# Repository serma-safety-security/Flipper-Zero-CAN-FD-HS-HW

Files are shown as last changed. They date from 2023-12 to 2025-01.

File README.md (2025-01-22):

# Flipper Zero CAN HS/FD Adapter

<div align="center">
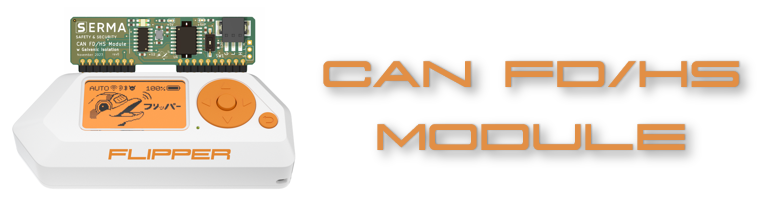
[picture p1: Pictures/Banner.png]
Banner
  
</div>

## Description: 

This project aims to develop a CAN (Controller Area Network) adapter for the Flipper Zero, allowing users to connect devices with a CAN interfaces in particular automotive ECU's.

## Firmware Development:

* The CAN adapter application firmware is developed in C++ using the Flipper Zero's Xtreme-Firmware SDK.
* The application firmware must runs on the Flipper Zero, which communicates with the CAN adapter through its SPI interface.

* Firmware features:
	- [x] CAN HS Communication
	- [ ] CAN FD Communication (partially)
    - [x] Device detection and configuration
	- [x] Error handling and debugging tools

* The CAN adapter is fully compatible with Linux SocketCAN enabling the usage of can-utils tooling for receiving and sending CAN messages. 

[See Software development folder for more information](https://github.com/serma-safety-security/Flipper-Zero-CAN-FD-HS-SW) 

## Hardware Development:

* The CAN adapter board is designed using KiCad 7.x
* The PCB layout includes:
	+ Microchip MCP2518FD CAN transceiver chip
	+ TJ1051i CAN driver with galvanic isolation up to 4kV 
	+ Screwless CAN connector for easy plug-in
	+ TX/RX CAN activity LEDs for easy debugging

[See Hardware development folder for more information](https://github.com/serma-safety-security/Flipper-Zero-CAN-FD-HS-HW/tree/main/Hardware)

## Getting Started:
* Download and install the CAN adapter application
* Launch the application and connect your Flipper Zero into your PC
* Find the appropriate COM port
* Setup the Flipper USB-CAN as a SocketCAN interface :

```sh
sudo modprobe can$ sudo modprobe can-raw$ sudo modprobe slcan
sudo slcan_attach -f -s6 -o “<COM Port> (e.g. :/dev/ttyACM0)”
sudo slcand“<COM Port> (e.g :/dev/ttyACM0)” can0
sudo ifconfig can0 up
```

**Connection:**

<div align="center">
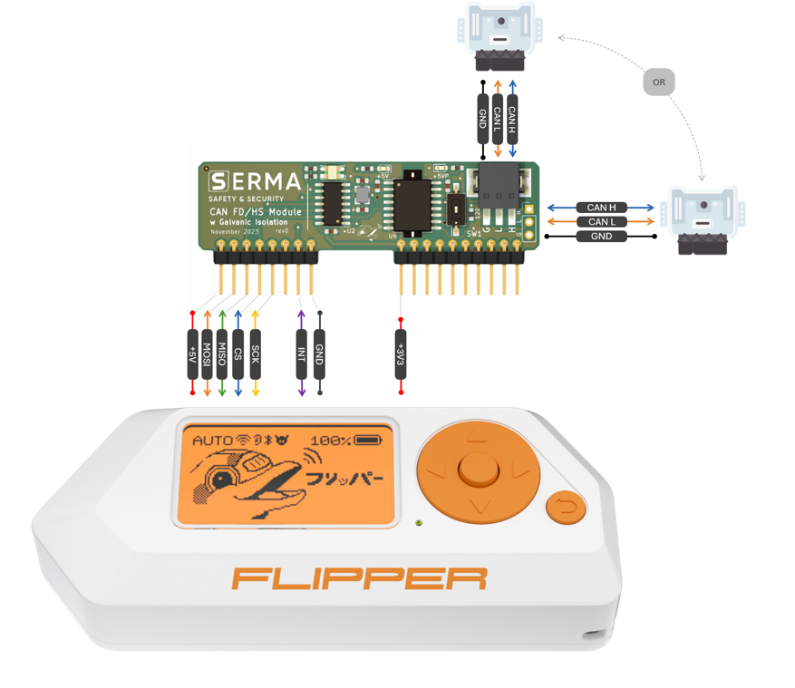
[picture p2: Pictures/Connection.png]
Wiring diagram
  
</div>

## Branches:

* `main`: The main branch, where stable code is kept. This is the default branch that new users will see when they clone the repository.
* `dev`: The development branch, where experimental or feature-in-progress code lives. This allows for concurrent development and testing without affecting the stability of the main branch.

## Contributing:

* Before contributing, please create a new issue to propose your changes.
* Fork this repository to create a copy of the original.
* Create a new branch from `dev` (e.g., `feature/my-new-firmware`) for your feature or fix.
* Make your changes and commit them with descriptive commit messages.
* Push your branch to your forked repository.
* Open a pull request against the original `dev` branch.

## License:

This project is licensed under the MIT See `LICENSE` file for details.

# Acknowledgments:

* Special thanks to Kévin for the SW dev and Morike for the HW dev !

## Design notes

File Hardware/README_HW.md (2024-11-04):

# Flipper Zero CAN FD HS 

<div align="center">
  
</div>

## Table of Contents
1. [Project Overview](#project-overview)
2. [Features](#features)
3. [Hardware Specifications](#hardware-specifications)
4. [Directory Structure](#directory-structure)
5. [Getting Started](#getting-started)
6. [Hardware Design Files](#hardware-design-files)
7. [Bill of Materials (BOM)](#bill-of-materials)
8. [Software & Firmware](#software--firmware)
9. [Testing & Debugging](#testing--debugging)
10. [Contributing](#contributing)
11. [License](#license)
12. [Contact](#contact)

---

## Project Overview

The Flipper Zero CAN FD/HS Module is an open-source hardware project focused on developing a custom electronic board that serves enables Flipper Zero to communicates with devices with a CAN interface. 

This repository contains the hardware design files, including schematics, PCB layout, and other resources necessary for the development and manufacturing of the board.

## Features
  - Supports both CAN 2.0B and CAN FD (up to 8 Mbps)
  - Compact design
  - Low power consumption
  - On-board 5V - 5V DCDC Regulator
  - Galvanic CAN Bus Isolation
  - TX/RX CAN Activity LED
  - Screwless CAN Connector    
 
## Hardware Specifications
- **CAN Controller:** MCP2518FD
- **CAN Transreceiver:** TJA1051i
- **Communication Interfaces:** SPI
- **Power Consumption:** [Idle, Active, etc.]
- **Dimensions:** 68mm x 18mm

## Board Pinout

<div align="center">
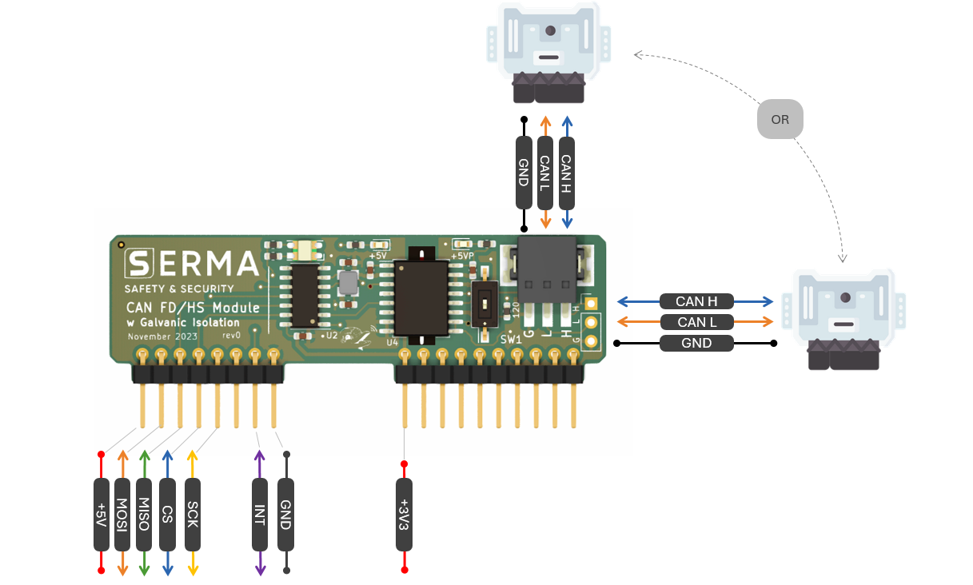
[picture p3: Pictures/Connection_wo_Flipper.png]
Pinout
  
</div>

## Directory Structure
```
├── /docs/                 # Documentation, guides, and tutorials
├── /hardware/             # Schematic, PCB layout files, gerber files
│   ├── /schematics/       # Schematics files (.pdf)
│   ├── /KiCAD Project/    # PCB & Schematic layout files (.brd, .sch)
│   ├── /gerbers/          # Gerber files for manufacturing
├── /bom/                  # Bill of Materials (BOM) files
└── README_HW.md           # Project documentation (this file)
```

## Getting Started
To start working on this project, clone the repository:
```bash
git clone https://github.com/yourusername/electronic-board-project.git
```

### Prerequisites
- **ECAD Tool**: [ See Getting started with Kicad v7 tutorial](https://docs.kicad.org/7.0/en/getting_started_in_kicad/getting_started_in_kicad.html) 

### Installation
1. Open the `Flipper_Zero_CAN_Module.kicad_pro` file using Kicad v7.x
2. Edit the schematic using the Schematic Editor
3. Edit the PCB using the Pcb Editor
3. Export gerber files from the PCB design if you wish to manufacture the board.

## Hardware Design Files
- **Schematic:** [Provide details about the schematic, link to key components, etc.]
- **PCB Layout:**   

<div align="center">
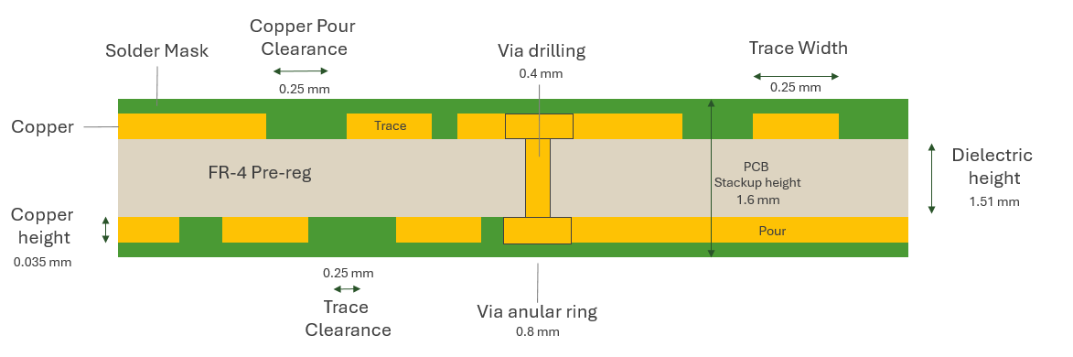
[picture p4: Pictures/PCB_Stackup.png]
PCB stackup
  
</div>

- **Gerber Files:** These files are located in `/hardware/gerbers/` and are used for manufacturing the board.

## Bill of Materials (BOM)

The Bill of Materials (BOM) is located in the `/bom/` folder. This includes a list of all components used in the design along with part numbers, quantities, and suppliers.
- Bills of materials is available for this distributor list : 
  - [x] Mouser
  - [x] LCSC
  - [ ] Radiospare
  
## Software & Firmware
[See Software development folder for more information](https://example.com/redirect) 

## Testing & Debugging
Work in progress..  

## Contributing
Contributions are welcome! Please follow these steps:
1. Fork the repository.
2. Create a new branch: `git checkout -b feature-branch`.
3. Make your changes and commit them.
4. Push to the branch: `git push origin feature-branch`.
5. Submit a pull request.

For large features or changes, consider creating an issue first to discuss the idea.

## License
This project is licensed under the TODO. See the [LICENSE](LICENSE) file for details.

---

Feel free to modify this template based on the specifics of your project!

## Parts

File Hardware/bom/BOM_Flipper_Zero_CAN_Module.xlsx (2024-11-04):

Bill of Materials
Project : | Flipper Zero CAN FD HS |  |  | N° AO : | TBD
Creation Date : | 2024-10-30
Print Date : | 2024-10-30
 |  |  |  |  |  |  | Sourcing 1 |  | Sourcing 2
Item Number | Reference | Description | Value | Quantity | Manufacturer Name | Manufacturer Part Number | Mouser Part Number | Mouser Unit Pricing | LCSC Part Number | LCSC Unit Pricing
1 | C1 | SMD 0603 Unpolarized Capacitor | 100nF | 1 | Murata Electronics | GCM188R71C104JA37D | 81-GCM188R71C104JA7D | 0.214 | C17540711 | 0.1123
 | C2 | SMD 0603 Unpolarized Capacitor | 22pF | 1 | Murata Electronics | GRT0335C1E220GA02D | 81-GRT0335C1E220GA2D | 0.093 | C22197519 | 0.0058
 | C3 | SMD 0603 Unpolarized Capacitor | 22pF | 1 | Murata Electronics | GRT0335C1E220GA02D | 81-GRT0335C1E220GA2D | 0.093 | C22197519 | 0.0058
 | C4 | SMD 0603 Unpolarized Capacitor | 100nF | 1 | Murata Electronics | GCM188R71C104JA37D | 81-GCM188R71C104JA7D | 0.214 | C17540711 | 0.1123
 | C5 | SMD 0603 Unpolarized Capacitor | 100nF | 1 | Murata Electronics | GCM188R71C104JA37D | 81-GCM188R71C104JA7D | 0.214 | C17540711 | 0.1123
 | C6 | SMD 0603 Unpolarized Capacitor | 4.7uF | 1 | Murata Electronics | GRM035R60E475ME01D | 81-GRM035R60E475ME1D | 0.18 | C21794777 | 0.0613
 | D2 | SMD Bicolor LED |  | 1 | Kingbright | KPB-3025ESGC-F01 | 604-KPB-3025ESGC-F01 |  | C5879346 | 0.2588
 | D3 | SMD 0603 Green LED |  | 1 | Vishay Semiconductors | TLMP1100-GS15 | 78-TLMP1100-GS15 | 0.51 | C20430351 | 0.2865
 | D4 | SMD 0603 Green LED |  | 1 | Vishay Semiconductors | TLMP1100-GS15 | 78-TLMP1100-GS15 | 0.51 | C20430351 | 0.2865
 | J1 | SMD 3pins female header | PTSM 0.5/ 3-2.5-H SMD R44 | 1 | Phoenix Contact | 1771033 | 651-1771033 | 0.76 | C3817179 | 0.8832
 | J2 | THT 3 pins 2.54mm male header |  | 1 | Molex | 90120-0123 | 538-90120-0123 | 0.76 | C6356254 | 0.3251
 | L1 | SMD Inductor | 22uH | 1 | TAIYO YUDEN | NRS5020T220MMGJ | 963-NRS5020T220MMGJ | 0.251 | C222921 | 0.146
 | R1 | SMD 0603 Resistor | 280 | 1 | Panasonic | ERJ-UP3F2800V | 667-ERJ-UP3F2800V | 0.223 | C1870036 | 0.0297
 | R2 | SMD 0603 Resistor | 130 | 1 | Panasonic | ERJ-UP3F1300V | 667-ERJ-UP3F1300V | 0.223 | C544047 | 0.0592
 | R3 | SMD 0603 Resistor | 130 | 1 | Panasonic | ERJ-UP3F1300V | 667-ERJ-UP3F1300V | 0.223 | C544047 | 0.0592
 | R4 | SMD 0603 Resistor | 280 | 1 | Panasonic | ERJ-UP3F2800V | 667-ERJ-UP3F2800V | 0.223 | C1870036 | 0.0297
 | R5 | SMD 0603 Resistor | 280 | 1 | Panasonic | ERJ-UP3F2800V | 667-ERJ-UP3F2800V | 0.223 | C1870036 | 0.0297
 | R6 | SMD 0603 Resistor | 120 | 1 | Panasonic | ERJ-P03F1200V | 667-ERJ-P03F1200V | 0.307 | C543223 | 0.0598
 | SW1 | SMD 1-DIP Switch |  | 1 | Omron Electronics | A6S-1104-H | 653-A6S1104H | 2.06 | C19843770 | 0.7302
 | U1 | Flipper Zero |  | 1 |  | FLIPPER_ZERO
 | U2 | SMD CAN FD HS SPI Driver |  | 1 | Microchip | MCP2518FDT-H/SL | 579-MCP2518FDT-H/SL | 1.89 | C626759 | 2.6841
 | U3 | SMD Isolated DC-DC |  | 1 | Murata Power Solutions | NXE1S0505MC | 580-NXE1S0505MC-R13 | 2.86 | C7321470 | 2.6841
 | U4 | SMD Galvanic isolation CAN transreceiver |  | 1 | NXP | TJA1052IT/2Y | 771-TJA1052IT/2Y | 6.36 | C92210
 | Y1 | SMD Oscillator |  | 1 | Abracon | ABM8-40.000MHZ-B2-T | 815-ABM8-40-B2-T | 0.409 |  | 4.2775
Total |  |  |  |  |  |  |  |  |  | 13.2391

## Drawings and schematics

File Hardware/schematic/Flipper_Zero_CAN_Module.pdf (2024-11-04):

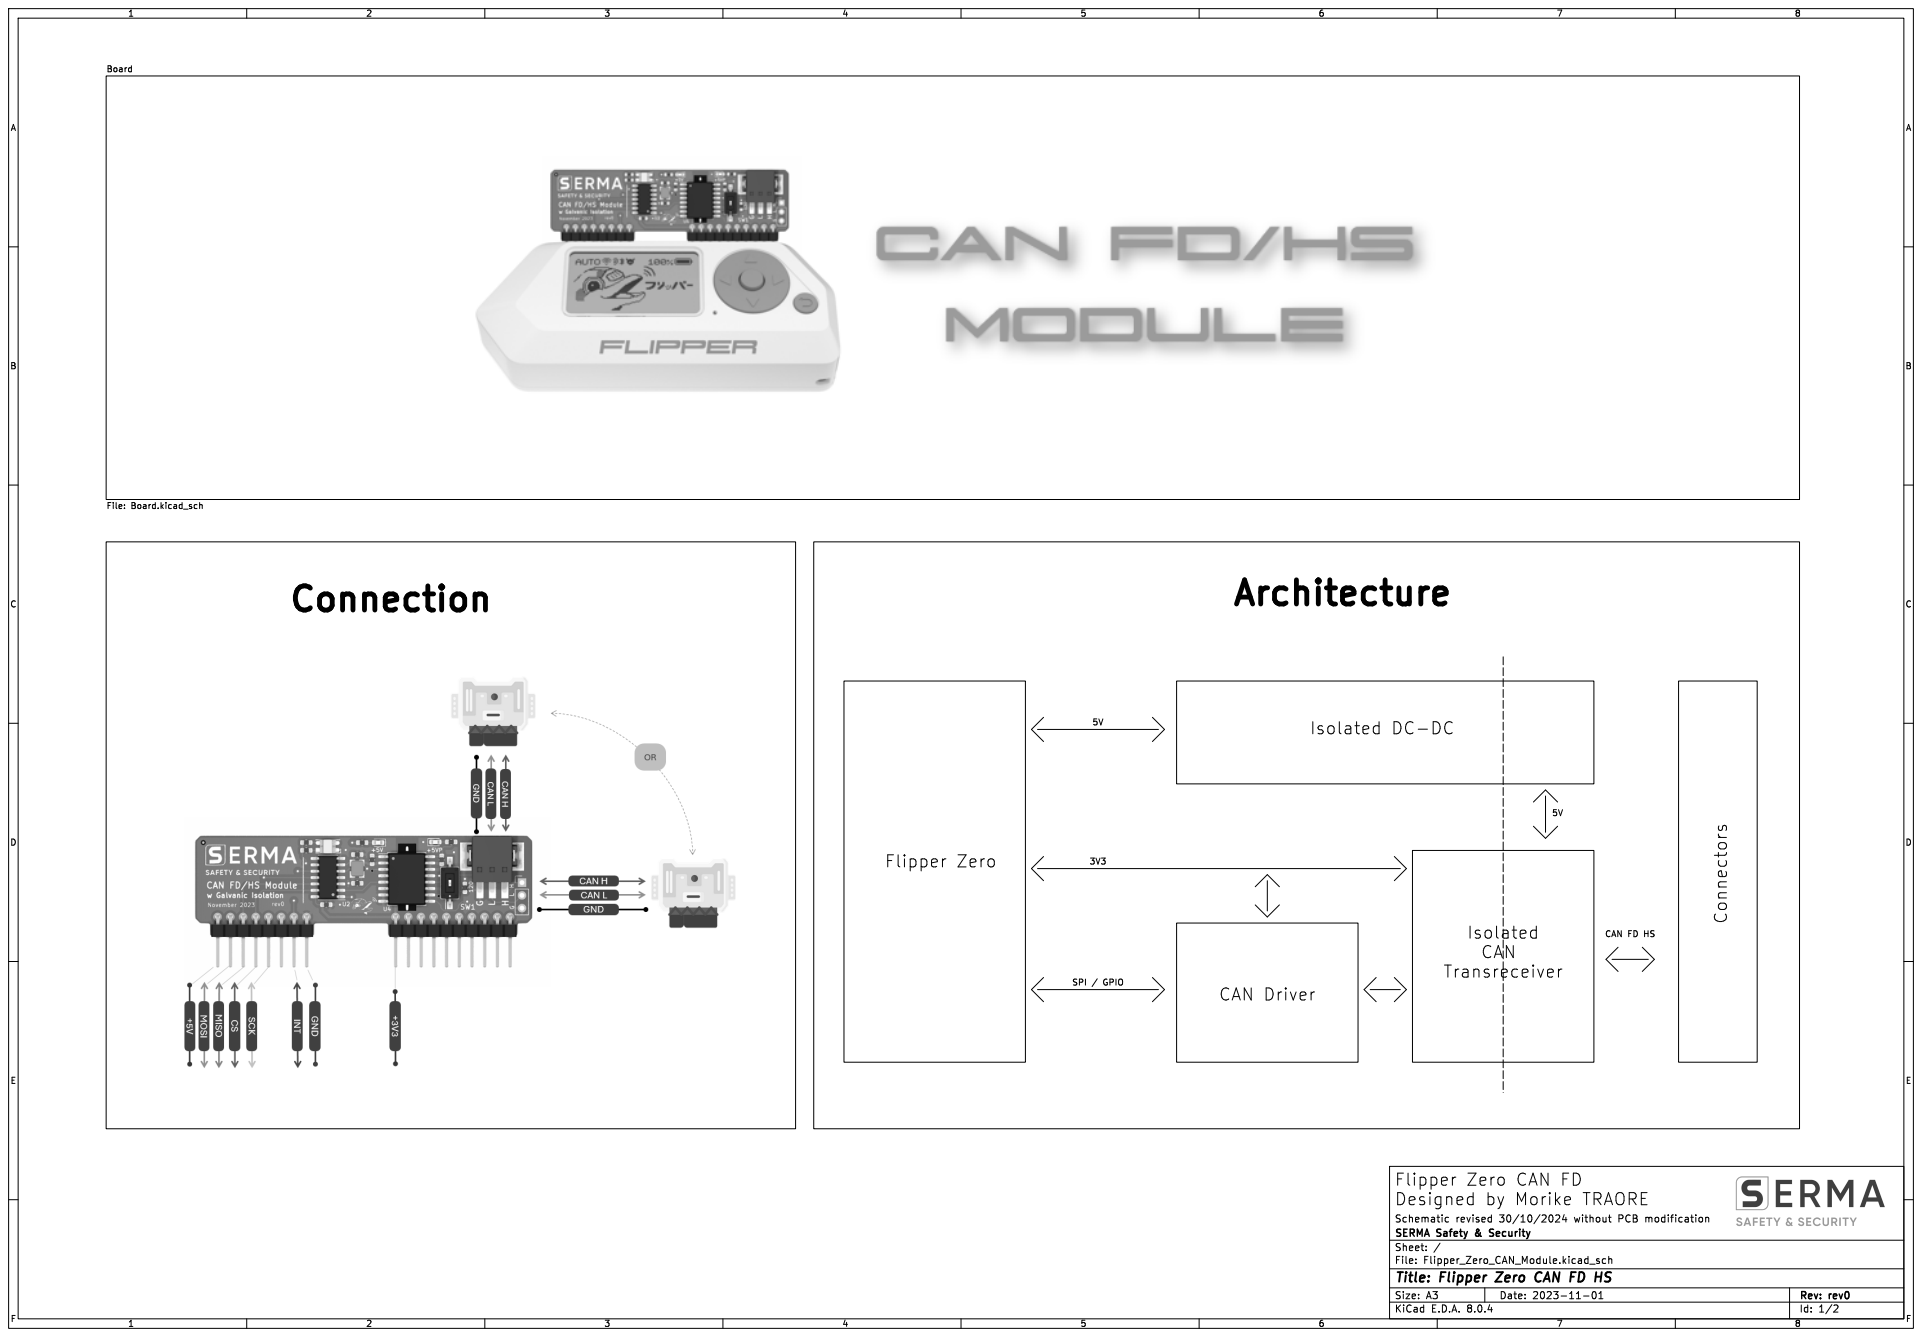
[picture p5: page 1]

CAN FD HS Connection

5V CAN Driver SPI / GPIO

Id: 1/2 Title: Flipper Zero CAN FD HS

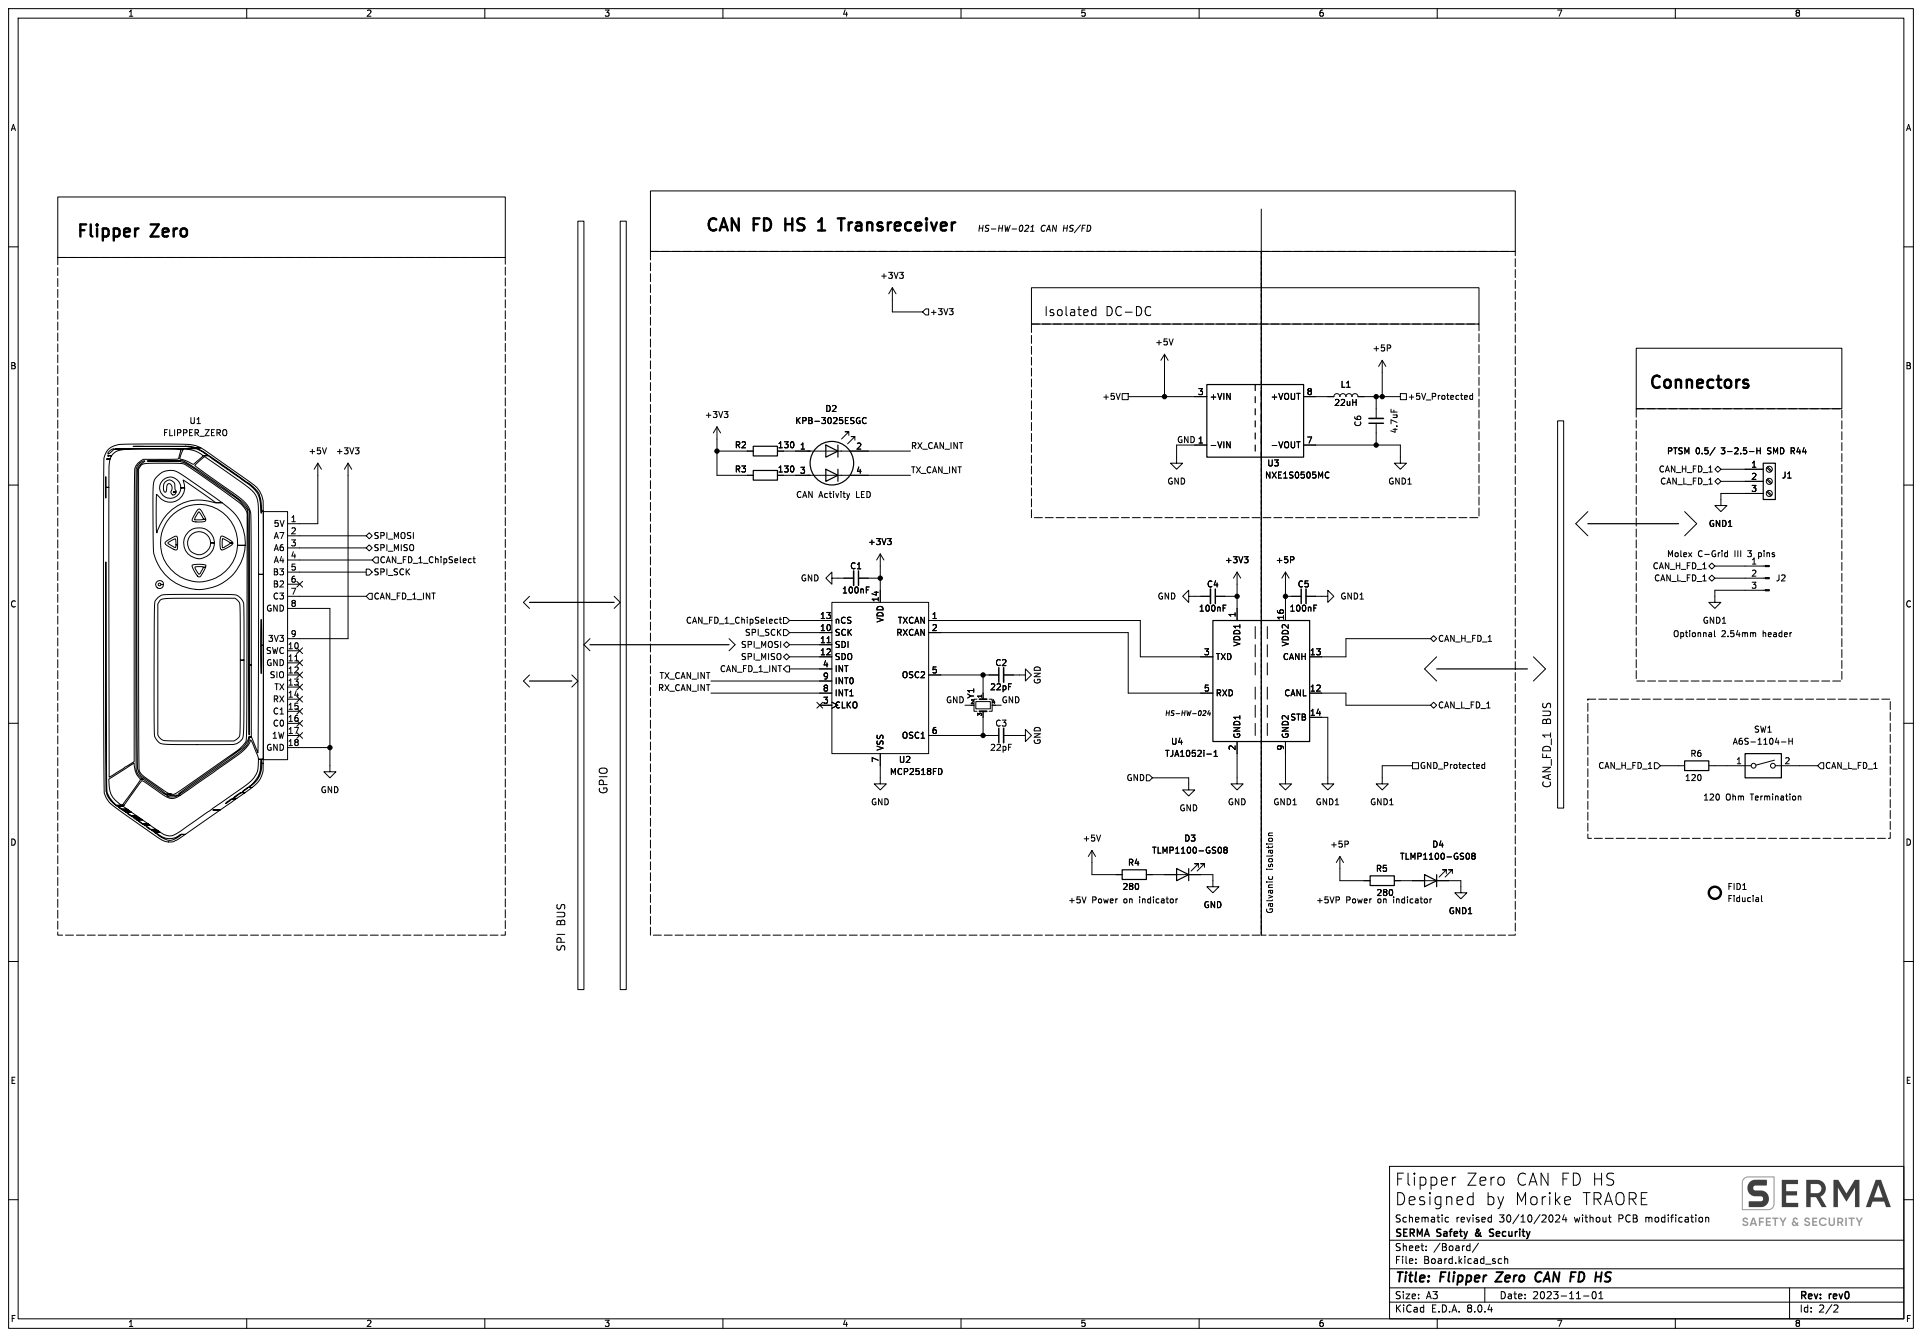
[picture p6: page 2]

CAN Activity LED Flipper Zero

100nF GND
TXCAN 1 SCK 10 SDI 11 SDO 12

Flipper Zero CAN FD HS

Id: 2/2 Title: Flipper Zero CAN FD HS

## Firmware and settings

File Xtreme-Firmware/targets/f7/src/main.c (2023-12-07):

#include <furi.h>
#include <furi_hal.h>
#include <flipper.h>
#include <alt_boot.h>
#include <update_util/update_operation.h>

#define TAG "Main"

int32_t init_task(void* context) {
    UNUSED(context);

    // Flipper FURI HAL
    furi_hal_init();

    // Init flipper
    flipper_init();

    return 0;
}

int main() {
    // Initialize FURI layer
    furi_init();

    // Flipper critical FURI HAL
    furi_hal_init_early();

    furi_hal_set_is_normal_boot(false);
    FuriThread* main_thread = furi_thread_alloc_ex("Init", 4096, init_task, NULL);

#ifdef FURI_RAM_EXEC
    // Prevent entering sleep mode when executed from RAM
    furi_hal_power_insomnia_enter();
    furi_thread_start(main_thread);
#else
    furi_hal_light_sequence("RGB");

    // Delay is for button sampling
    furi_delay_ms(100);

    FuriHalRtcBootMode boot_mode = furi_hal_rtc_get_boot_mode();
    if(boot_mode == FuriHalRtcBootModeDfu || !furi_hal_gpio_read(&gpio_button_left)) {
        furi_hal_light_sequence("rgb WB");
        furi_hal_rtc_set_boot_mode(FuriHalRtcBootModeNormal);
        flipper_boot_dfu_exec();
        furi_hal_power_reset();
    } else if(boot_mode == FuriHalRtcBootModeUpdate) {
        furi_hal_light_sequence("rgb BR");
        // Do update
        flipper_boot_update_exec();
        // if things go nice, we shouldn't reach this point.
        // But if we do, abandon to avoid bootloops
        furi_hal_rtc_set_boot_mode(FuriHalRtcBootModeNormal);
        furi_hal_power_reset();
    } else if(!furi_hal_gpio_read(&gpio_button_up)) {
        furi_hal_light_sequence("rgb WR");
        flipper_boot_recovery_exec();
        furi_hal_power_reset();
    } else {
        furi_hal_light_sequence("rgb G");
        if(boot_mode != FuriHalRtcBootModePostUpdate && boot_mode != FuriHalRtcBootModePreUpdate) {
            furi_hal_set_is_normal_boot(true);
        }
        furi_thread_start(main_thread);
    }
#endif

    // Run Kernel
    furi_run();

    furi_crash("Kernel is Dead");
}

void Error_Handler(void) {
    furi_crash("ErrorHandler");
}

void abort() {
    furi_crash("AbortHandler");
}

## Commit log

2023-11-09 Adding picture of the board
2023-11-10 Uploading design files
    [BOM_Flipper_Zero_CAN_Module.xlsx]
2023-12-04 add Xtreme firmware
    [api_symbols.csv]
2024-03-11 Uploading up to date schematic version.
2024-03-11 Uploading up-to-date Bill of Materials
    [BOM_Flipper_Zero_CAN_Module.xlsx]
2024-03-11 Add new directory to store KiCAD project.
2024-03-11 Upload KiCAD Project Archive.
2024-11-04 Updating hardware design files
    [BOM_Flipper_Zero_CAN_Module.xlsx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]
